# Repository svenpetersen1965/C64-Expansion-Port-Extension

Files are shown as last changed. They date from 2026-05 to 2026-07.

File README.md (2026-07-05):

This is an extension cable thing for the C64 Expansion Port, consisting of two PCBs, one fits into the C64, the other provices an expansion port connector, which are connected via a ribbon cable. 

Rev. 0 of this project is now built and tested. A 25cm ribbon cable is good, a 100cm ribbon cable is too long.

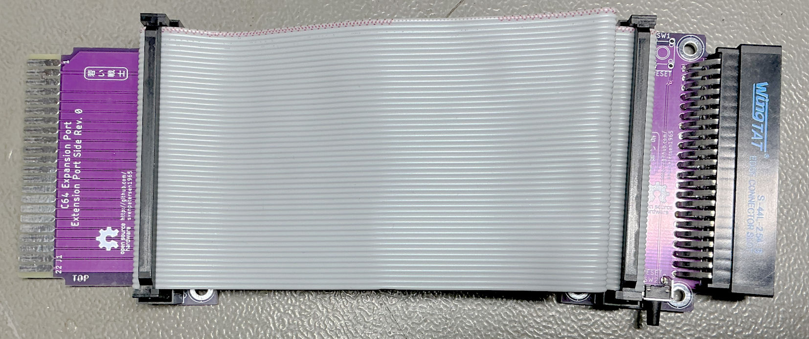
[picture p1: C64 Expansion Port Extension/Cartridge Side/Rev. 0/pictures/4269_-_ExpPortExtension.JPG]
Expansion Port Extansion


For User Port and Cassette Port Extension Cable see: <a href="https://github.com/svenpetersen1965/Commodore-Port-Breakout">Commodore Port Breakout</a>

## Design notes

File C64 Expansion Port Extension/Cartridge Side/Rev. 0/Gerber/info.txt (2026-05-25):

      
       Board: C64 Exp cartridge
       Rev.:  0
  
       Files:
       ======
  
       All Gerber files are generated in extended gerber format (RS274X)
       *.TOP        : Film top copper
       *.BOT        :  -"- bottom copper
       *.STC        :  -"- top soldermask 
       *.STS        :  -"- bottom soldermask
       *.PLC        :  -"- silk screen top
       *.PLS        :  -"- silk screen bottom
       *.DK         : Drills plated Through (Excellon)
       *.NDK        : Drills not plated Through (Excellon)
       *.OUT        : Board outline

       Board Size:
       ===========
       Length     :   72.0 mm
       Width      :   48.0 mm
       Thickness  :   1.6 mm
       Material   :   FR 4
       Copper     :   35 um
       Surface    :   HASL
       
       Remarks:
       ========

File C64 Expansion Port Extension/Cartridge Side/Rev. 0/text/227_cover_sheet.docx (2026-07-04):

Project Documentation

C64 Expansion Board Extension
Cartridge Side

Project number: 227

Revision: 0

Date: 25.05.2026


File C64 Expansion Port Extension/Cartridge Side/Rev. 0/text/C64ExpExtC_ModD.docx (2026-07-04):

C64 Expansion Port Extension Cartridge Side Rev. 0

Module Description

# Introduction

The purpose of the C64 Expansion Port Extension is to place an Expansion Port connector at a desired location and connect the actual C64 Expansion Port via a ribbon cable. The maximum length of said ribbon cable is not yet determined it is >25cm and <100 cm. This board is providing the cartridge connector and a reset switch (two possible positions).

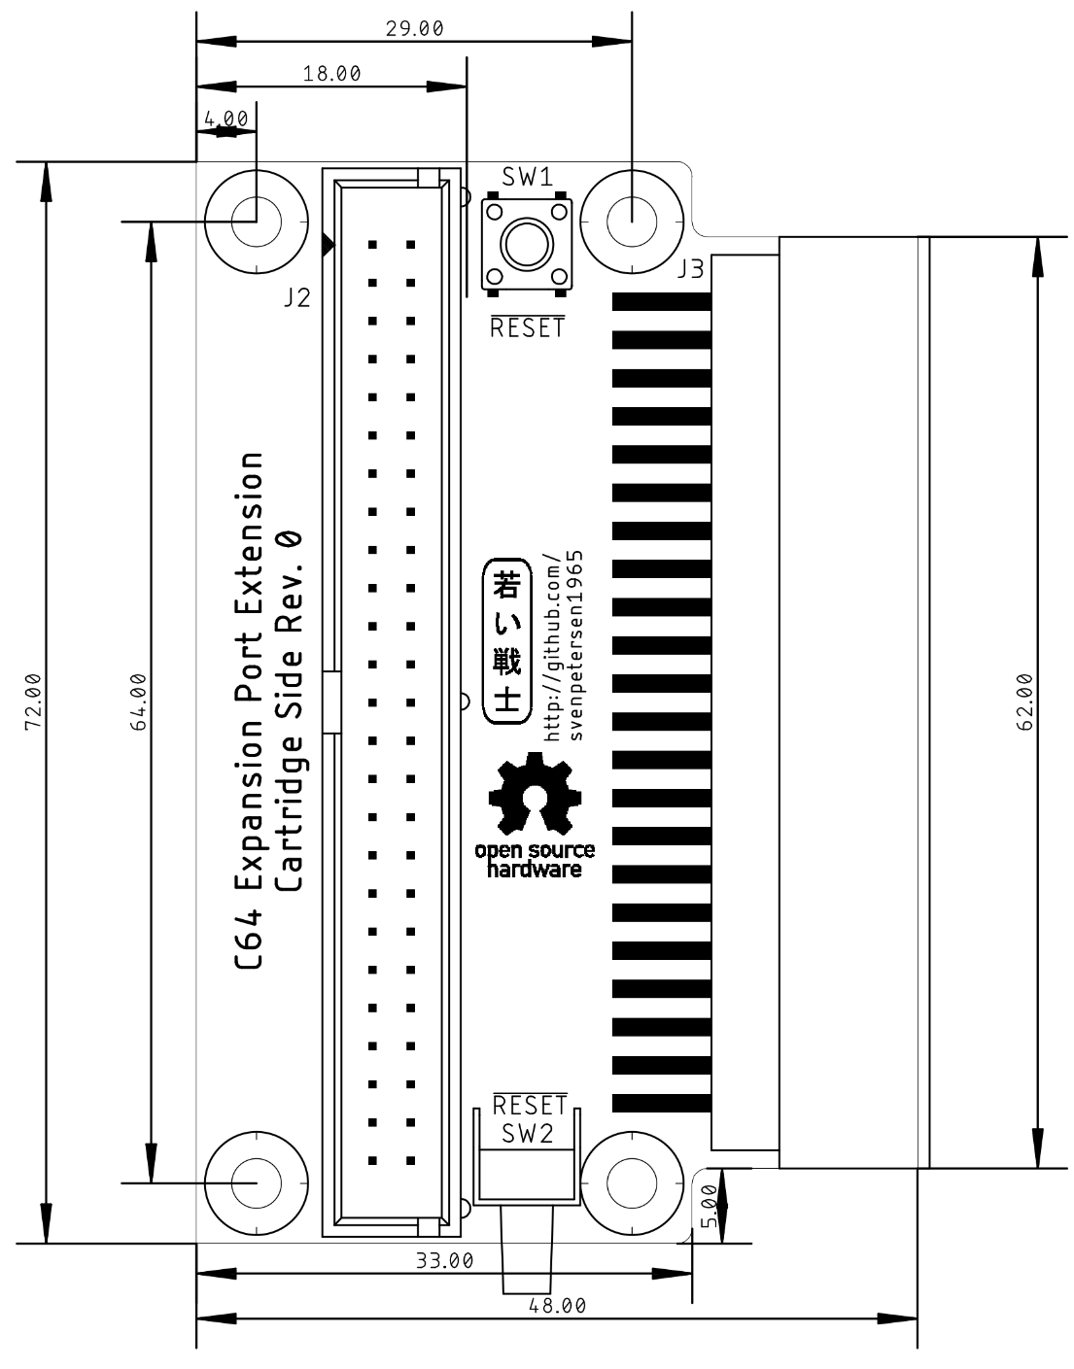
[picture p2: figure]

Figure 1: Dimension of the cartridge side PCB

# Connector Pinouts

## J2 – Break out connector

2x25 box header, 2.54mm pitch

Pin | Signal | Pin | Signal
1 | GND | 2 | GND
3 | +5V | 4 | GND
5 | +5V | 6
7 | +5V | 8
9 | | 10
11 | R / | 12 | PHI2
13 | DOT CLOCK | 14 | A15
15 | | 16 | A14
17 | | 18 | A13
19 | | 20 | A12
21 | | 22 | A11
23 | | 24 | A10
25 | BA | 26 | A9
27 | | 28 | A8
29 | D7 | 30 | A7
31 | D6 | 32 | A6
33 | D5 | 34 | A5
35 | D4 | 36 | A4
37 | D3 | 38 | A3
39 | D2 | 40 | A2
41 | D1 | 42 | A1
43 | D0 | 44 | A0
45 | GND | 46 | GND
47 | GND | 48 | GND
49 | GND | 50 | GND

## J3 – Cartridge Connector

Card Edge Connector 22x2P 2.54mm (0.1“) Right Angle

Pin (TOP) | Signal | Pin | Signal (BOT)
1 | GND | A | GND
2 | +5V | B
3 | +5V | C
4 | | D
5 | R / | E | PHI2
6 | DOT CLOCK | F | A15
7 | | H | A14
8 | | J | A13
9 | | K | A12
10 | | L | A11
11 | | M | A10
12 | BA | N | A9
13 | | P | A8
14 | D7 | R | A7
15 | D6 | S | A6
16 | D5 | T | A5
17 | D4 | U | A4
18 | D3 | V | A3
19 | D2 | W | A2
20 | D1 | X | A1
21 | D0 | Y | A0
22 | GND | Z | GND

# Revision History

## Rev. 0

The prototype is functional with a 25cm ribbon cable.

See test description (Doc.-No. 227-6-02-00)

C64ExpExtC_ModD.docx 04.07.2026 12:59 Drafted by Sven Petersen Page 2 of 2 Doc.-No.: 227-6-01-00

C64ExpExtC_ModD.docx 04.07.2026 12:59 Drafted by Sven Petersen Page 1 of 1 Doc.-No.: 227-6-01-00

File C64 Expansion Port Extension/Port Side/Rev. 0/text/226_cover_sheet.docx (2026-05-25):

Project Documentation

C64 Expansion Board Extension
Port Side

Project number: 226

Revision: 0

Date: 25.05.2026

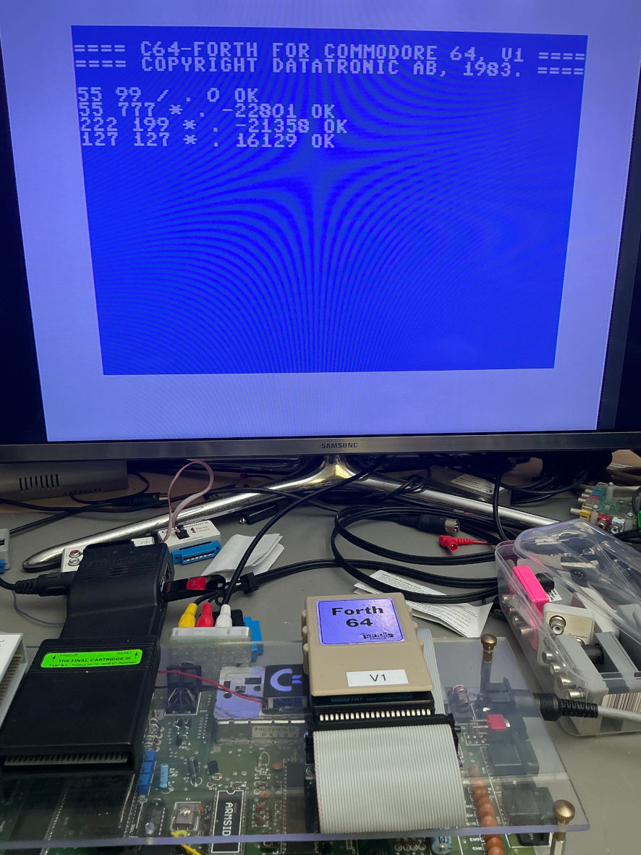
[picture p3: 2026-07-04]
C64 Expansion Port Extension/Cartridge Side/Rev. 0/pictures/4263_-_Forth64_25.JPG

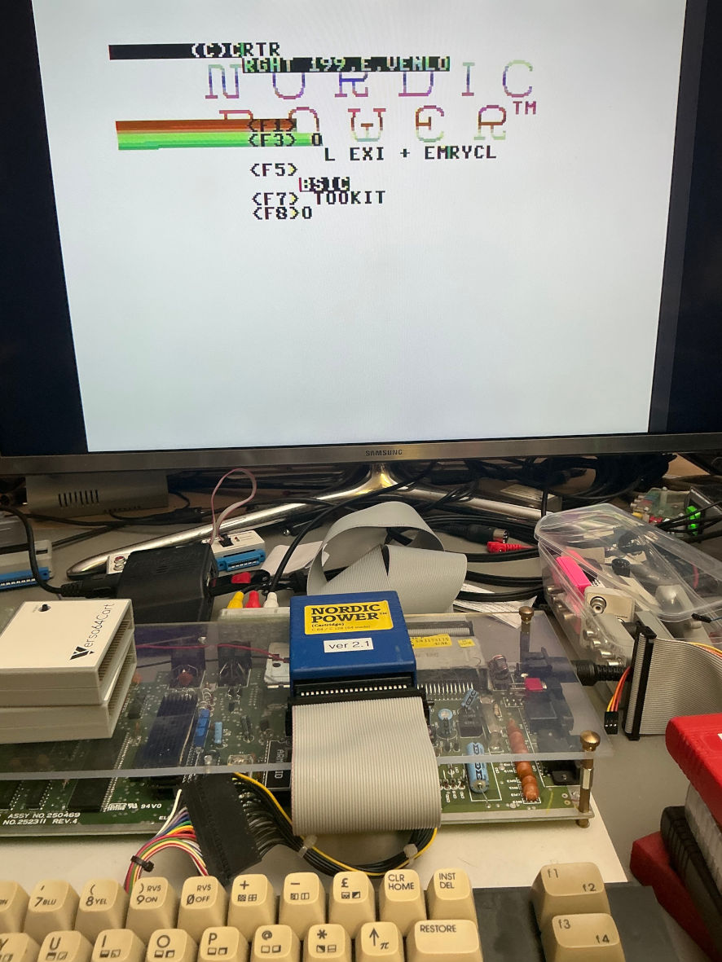
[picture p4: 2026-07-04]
C64 Expansion Port Extension/Cartridge Side/Rev. 0/pictures/4258_-_NordicPower21_100_fail.JPG

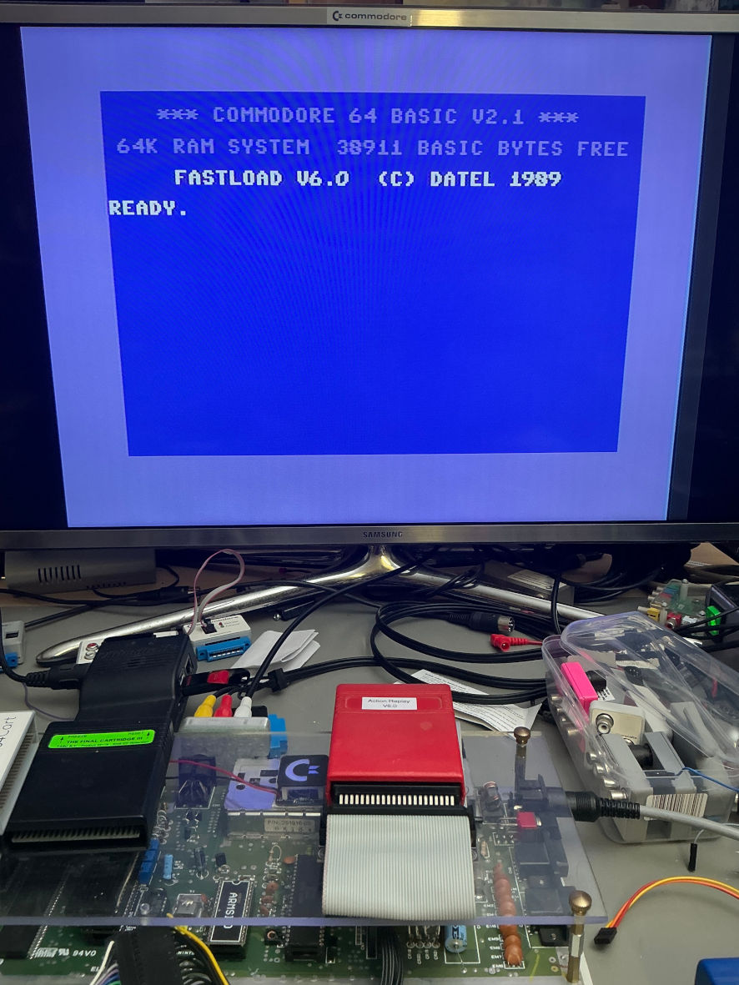
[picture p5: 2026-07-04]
C64 Expansion Port Extension/Cartridge Side/Rev. 0/pictures/4261_-_ActionaReplay25.JPG

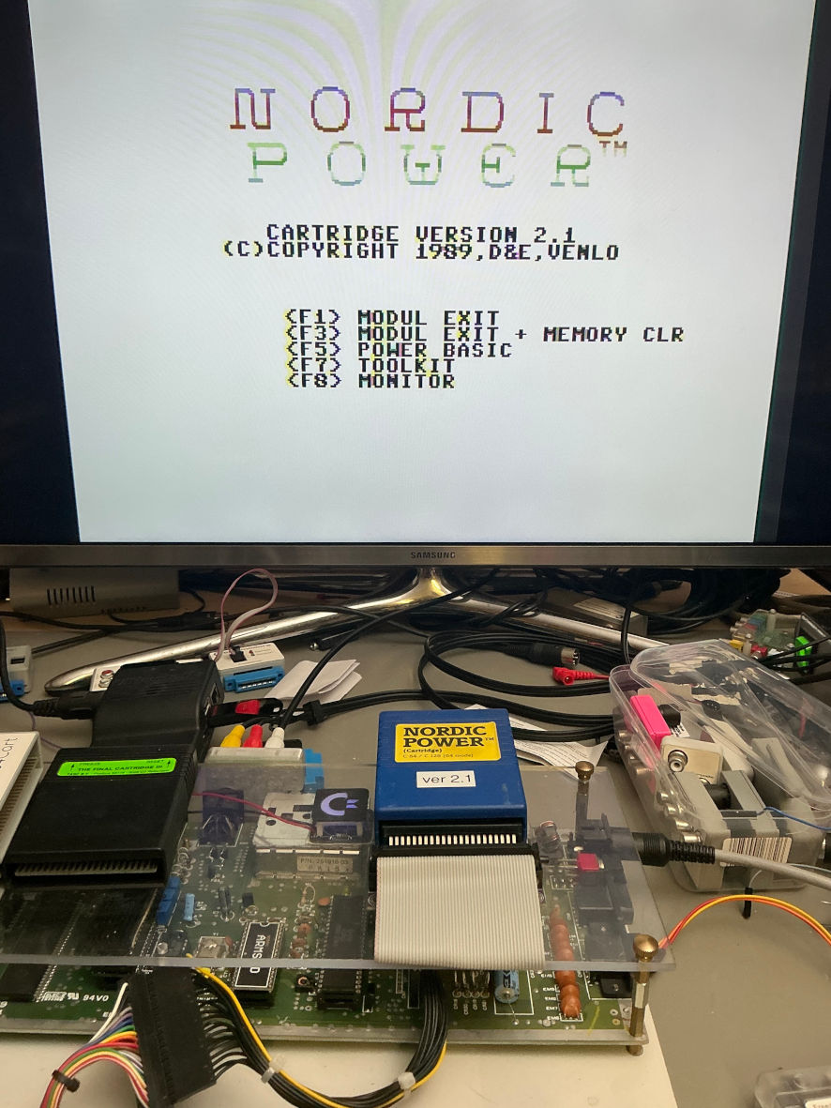
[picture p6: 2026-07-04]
C64 Expansion Port Extension/Cartridge Side/Rev. 0/pictures/4260_-_NordicPower21_25.JPG

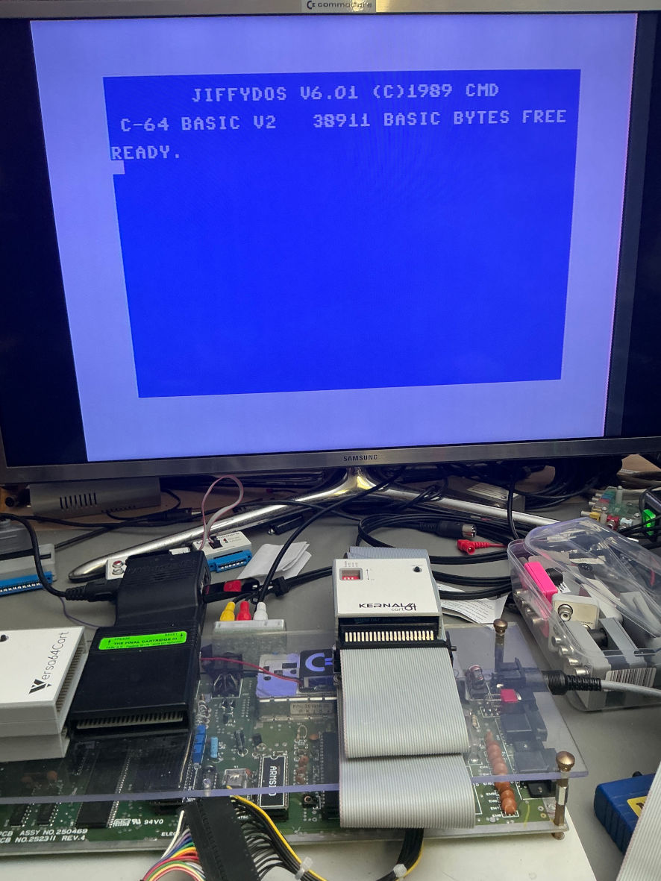
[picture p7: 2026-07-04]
C64 Expansion Port Extension/Cartridge Side/Rev. 0/pictures/4265_-_Kernal64cart100.JPG

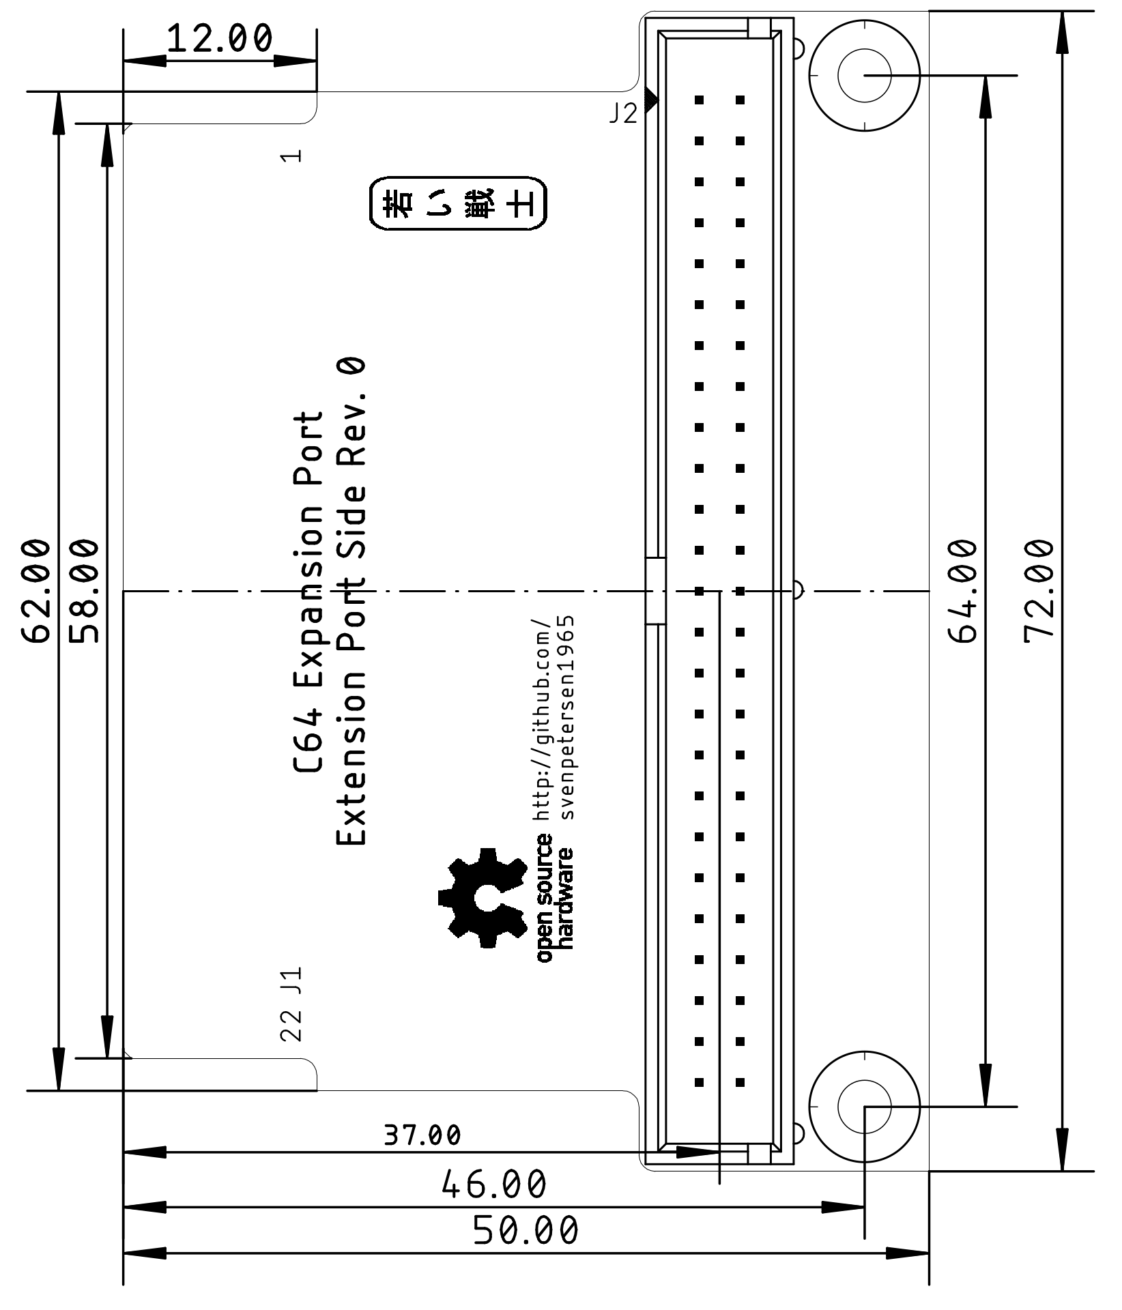
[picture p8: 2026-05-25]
C64 Expansion Port Extension/Port Side/Rev. 0/Pictures/dimensions.png

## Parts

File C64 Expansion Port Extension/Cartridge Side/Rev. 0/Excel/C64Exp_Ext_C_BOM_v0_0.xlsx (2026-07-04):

C64 Expansion Port Extension Cartridge Side Rev. 0
Bill of Material Rev. 0.0
Pos. | Qty | Value | Footprint | Ref.-No. | Comment
1 | 1 | 227-2-01-00 | 2 Layer | PCB Rev. 0 | 2 layer, Cu 35µ, HASL, 72.0mm x 48.0mm, 1.6mm FR4
2 | 1 | 2x25 boxed header | 2X25WV | J2 | 2x25, boxed pin header, e.g. reichelt.de WSL 40G
3 | 1 | 2x22 pin edge connector, 90° | EXPANSION_OUT | J3 | 1/5 x 5pc Industrial Card Edge Slot Socket Connector 22x2P 44P 2.54mm 0.1" Right Angle (https://de.aliexpress.com/item/33029458127.html?sourceType=1)
4 | 1 | JPT1236HB | JTP_1236HB | SW2 | 90° alternative reset switch, AliExpress search term "tact switch 90°"
5 | 1 | JTP-1130 | JTP-1130 | SW1 | Standard 6x6mm tact switch, e.g. Namae JTP-1130 or any other 6x6 tact switch, e.g. reichelt.de JTP-1130 or AliExpress search term "tact switch"
6 | 2 | 2x50 ribbon cable connector, 2.54mm |  |  | See drawing number 227-3-01-00, e.g. reichelt.de PFL 50
7 | 1 | 25cm 50 way AWG28, 1.27mm |  |  | ribbon cable

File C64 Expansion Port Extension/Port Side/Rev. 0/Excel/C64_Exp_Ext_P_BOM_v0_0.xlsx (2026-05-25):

C64 Expansion Port Extension Port Side Rev. 0
Bill of Material Rev. 0.0
Pos. | Qty | Value | Footprint | Ref.-No. | Comment
1 | 1 | 226-2-01-00 | 2 Layer | PCB Rev. 0 | 2 layer, Cu 35µ, HASL, 72.0mm x 50.0mm, 1.6mm FR4
 | 1 | 2x25 box header, 2.54mm | 2X25WV | J2 | 2x25, boxed pin header, e.g. reichelt.de WSL 50G

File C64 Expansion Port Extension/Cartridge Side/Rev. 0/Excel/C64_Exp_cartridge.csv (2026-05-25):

Qty | Value | Device | Package | Parts | Description
4 |  | BOHR3,3 | BOHR3,3 | DRL1, DRL2, DRL3, DRL4
1 |  | PINHD-2X25BOX | 2X25WV | J2
1 | C64-EXPANSION_F | C64-EXPANSION_F | EXPANSION_OUT | J3
1 | JPT1236HB | JPT1236HB | JTP_1236HB | SW2
1 | JTP-1130 | JTP-1130 | JTP-1130 | SW1
1 | OPEN_SOURCE_HW | OPEN_SOURCE_HW | OPENHW | U$22

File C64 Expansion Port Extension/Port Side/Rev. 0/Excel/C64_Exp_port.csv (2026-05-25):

Qty | Value | Device | Package | Parts | Description
2 |  | BOHR3,3 | BOHR3,3 | DRL1, DRL2
1 |  | PINHD-2X25BOX | 2X25WV | J2
1 | C64-EXPANSIONP | C64-EXPANSIONP | EXPPORT | J1
1 | OPEN_SOURCE_HW | OPEN_SOURCE_HW | OPENHW | U$22

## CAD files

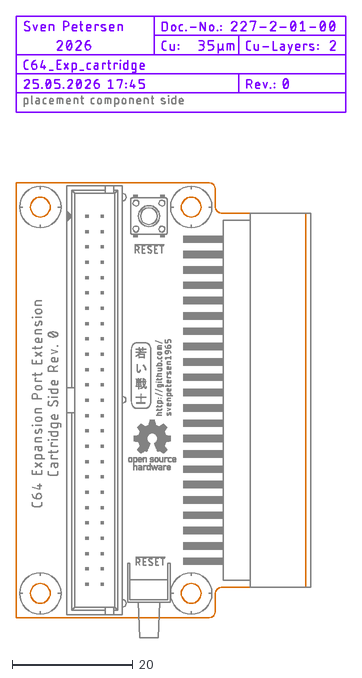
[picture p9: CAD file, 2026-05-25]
C64 Expansion Port Extension/Cartridge Side/Rev. 0/dxf/C64_Exp_cartridge.dxf
54.6 x 103.0

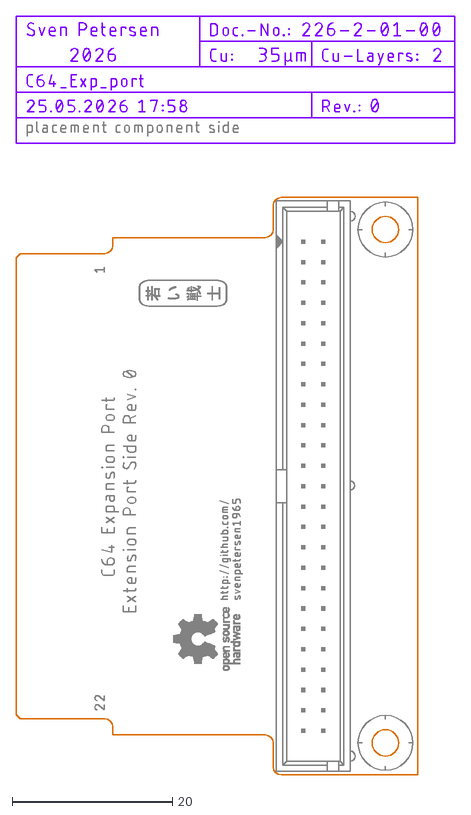
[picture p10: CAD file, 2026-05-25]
C64 Expansion Port Extension/Port Side/Rev. 0/dxf/C64_Exp_port.dxf
54.6 x 94.6

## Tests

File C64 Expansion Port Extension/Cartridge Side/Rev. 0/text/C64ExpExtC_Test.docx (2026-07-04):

C64 Expansion Port Extension Cartridge Side Rev. 0

Test Description

# Test Setup

- C64 short board
- C64 Expansion Port Extension, Port Side & Cartridge Side PCB Rev. 0
- Two 50-way ribbon cables, the lengths are 25cm and 100cm
- A variety of cartridges

# Test Execution

The complete Expansion Port Extension was connected to the C64 expansion port on one side and the cartridge on the other side. Then, the C64 was switched on and different functions of the cartridge were tested.

Cartridge | 25cm cable | 100cm cable
Versa64cart | ☑ | ☑
Easy Flash | ☑ | ☑
Kung Fu Flash | ☑ | ☑
Epyx Fastload | ☑ | ☑
The Final Cartridge III | ☑ | ☑
Ultimate II+ | ☑ | ☑
The Final Cartridge III+ | ☑ | ☒
Forth 64 | ☑ | ☒
Nordic Power 7.2 | ☑ | ☒
Nordic Power 2.1 | ☑ | ☒
Action Replay 6.0 | ☑ | ☒
Ms PAC-MAN | ☑ | ☒
Power Cartridge | ☑ | ☑

# Conclusion

The Expansion Port Extension Rev. 0 is functional. The cable length is influencing the proper function of the cartridge, though. A 25cm ribbon cable is always working, a 100cm ribbon cable is not recommended. The maximum cable length rages between those lengths.

C64ExpExtC_Test.docx 04.07.2026 12:58 Drafted by Sven Petersen Page 2 of 2 Doc.-No.: 227-6-01-00

C64ExpExtC_Test.docx 04.07.2026 12:58 Drafted by Sven Petersen Page 1 of 1 Doc.-No.: 227-6-02-00

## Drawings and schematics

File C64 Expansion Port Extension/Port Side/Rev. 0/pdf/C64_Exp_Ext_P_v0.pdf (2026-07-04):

# Project Documentation

## C64 Expansion Board Extension Port Side

## Project number: 226

## Revision: 0

## Date: 25.05.2026

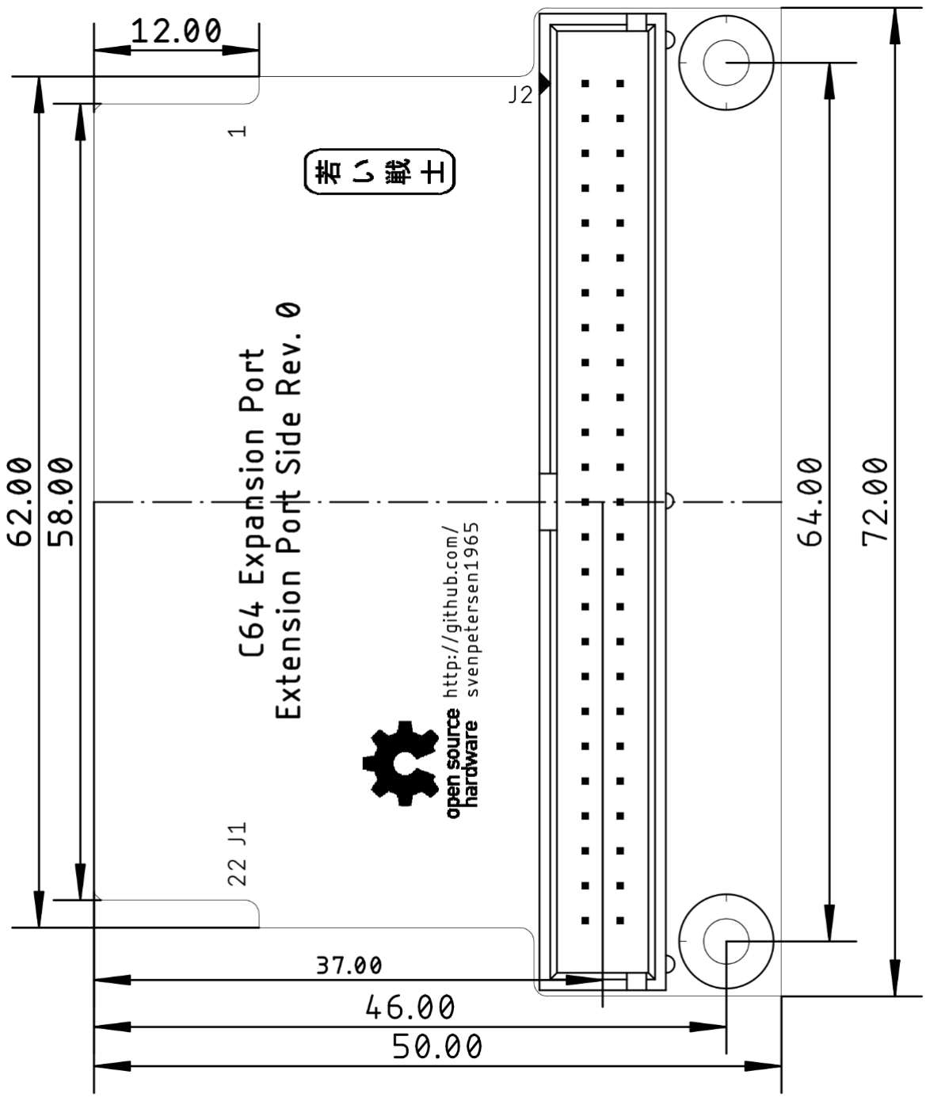
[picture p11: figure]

C64ExpExtP_ModD.docx | | 04.07.2026 13:01
Drafted by Sven Petersen | Page 1 of 3 | Doc.-No.: 226-6-01-00

### C64 Expansion Port Extension Port Side Rev. 0

### Module Description

## Introduction

The purpose of the C64 Expansion Port Extension is to place an Expansion Port connector at a desired location and connect the actual C64 Expansion Port via a ribbon cable. The maximum length of said ribbon cable is not yet determined. This board is connected to the C64 itself.

Figure 1: Dimension of the port side PCB

C64ExpExtP_ModD.docx | | 04.07.2026 13:01
Drafted by Sven Petersen | Page 2 of 3 | Doc.-No.: 226-6-01-00

## Connector Pinouts

### J1 – Expansion Port

Pin (TOP) Signal | Pin Signal (BOT)
1 | GND | A | GND
2 | +5V | B | ROMH
3 | +5V | C | RESET
4 | IRQ | D | NMI
5 | R / W | E | PHI2
6 | DOT CLOCK | F | A15
7 | I/O1 | H | A14
8 | GAME | J | A13
9 | EXROM | K | A12
10 | I/O2 | L | A11
11 | ROML | M | A10
12 | BA | N | A9
13 | DMA | P | A8
14 | D7 | R | A7
15 | D6 | S | A6
16 | D5 | T | A5
17 | D4 | U | A4
18 | D3 | V | A3
19 | D2 | W | A2
20 | D1 | X | A1
21 | D0 | Y | A0
22 | GND | Z | GND

### J2 – Break out connector

2x25 box header, 2.54mm pitch

Pin Signal | Pin Signal
1 | GND | 2 | GND
3 | +5V | 4 | GND
5 | +5V | 6 | ROMH
7 | +5V | 8 | RESET
9 | IRQ | 10 | NMI
11 | R / W | 12 | PHI2
13 | DOT CLOCK | 14 | A15
15 | I/O1 | 16 | A14
17 | GAME | 18 | A13
19 | EXROM | 20 | A12

C64ExpExtP_ModD.docx | | 04.07.2026 13:01
Drafted by Sven Petersen | Page 3 of 3 | Doc.-No.: 226-6-01-00
Pin Signal | Pin Signal
21 | I/O2 | 22 | A11
23 | ROML | 24 | A10
25 | BA | 26 | A9
27 | DMA | 28 | A8
29 | D7 | 30 | A7
31 | D6 | 32 | A6
33 | D5 | 34 | A5
35 | D4 | 36 | A4
37 | D3 | 38 | A3
39 | D2 | 40 | A2
41 | D1 | 42 | A1
43 | D0 | 44 | A0
45 | GND | 46 | GND
47 | GND | 48 | GND
49 | GND | 50 | GND

## Revision History

### Rev. 0

The prototype is functional with a 25cm cable

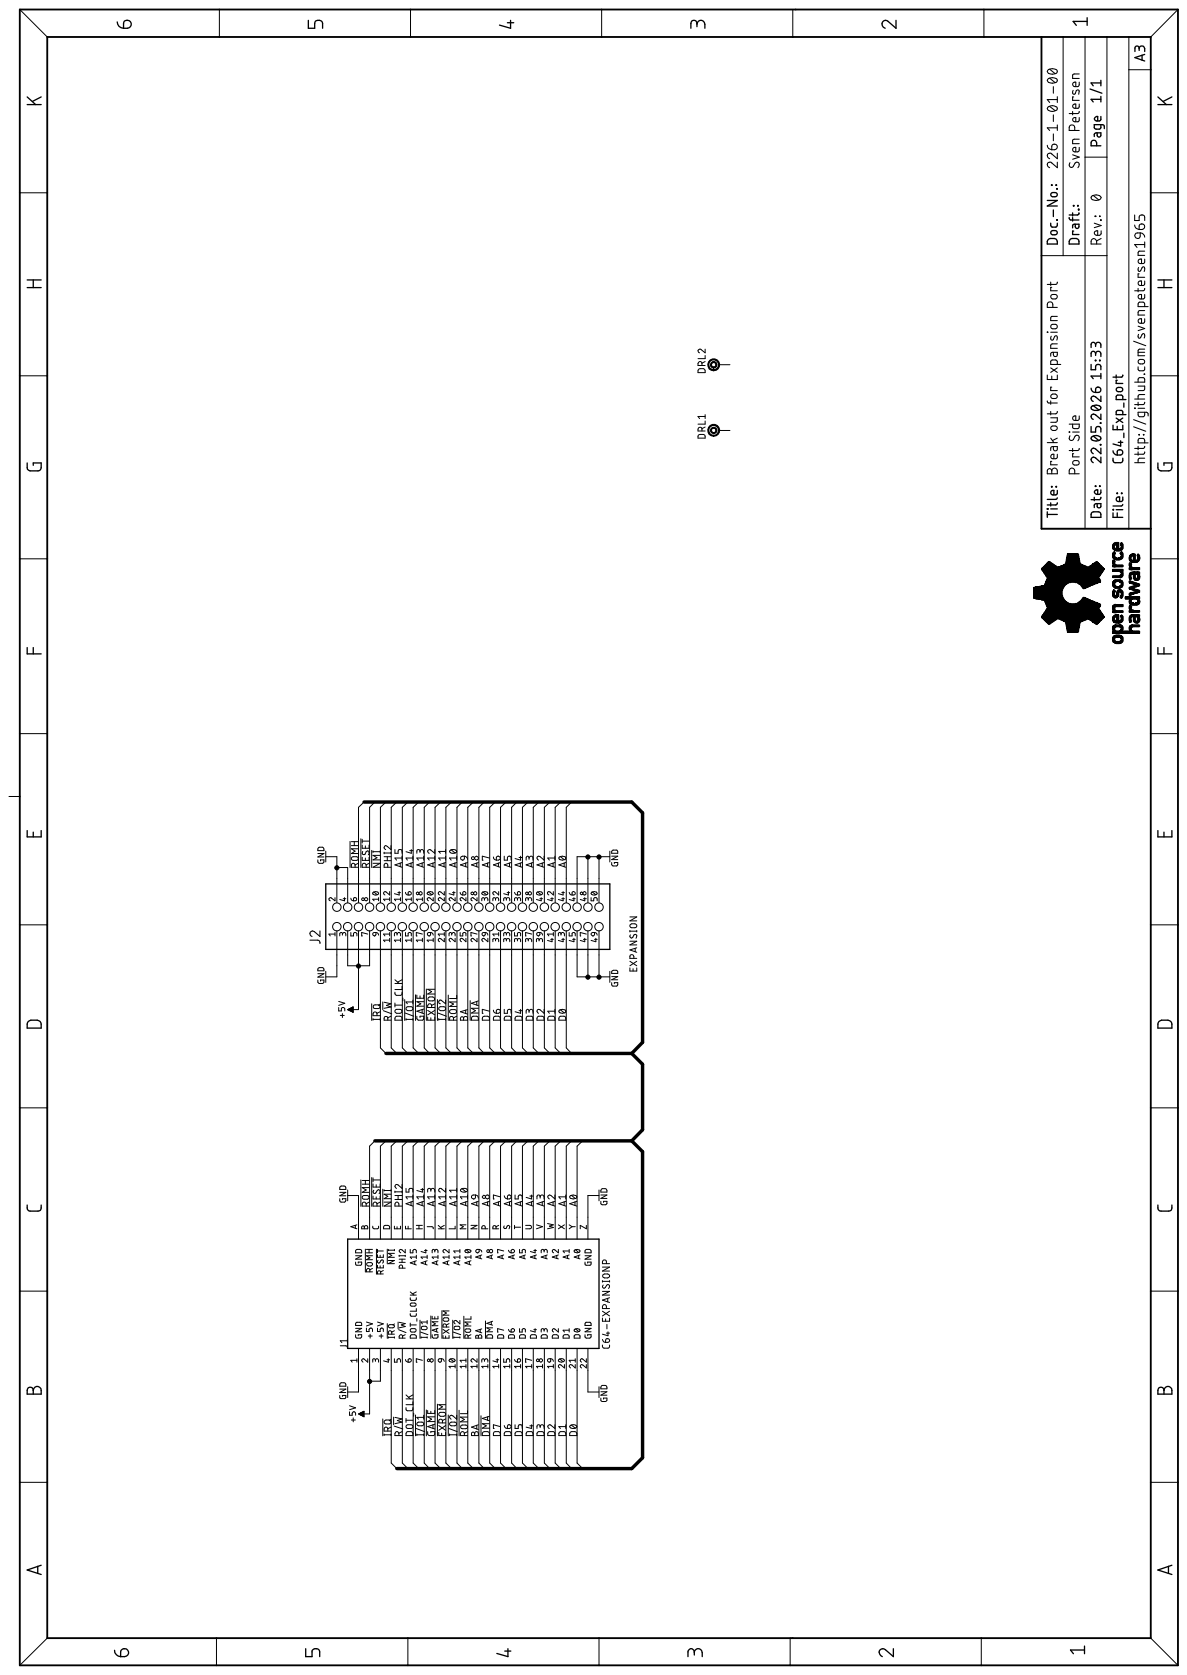
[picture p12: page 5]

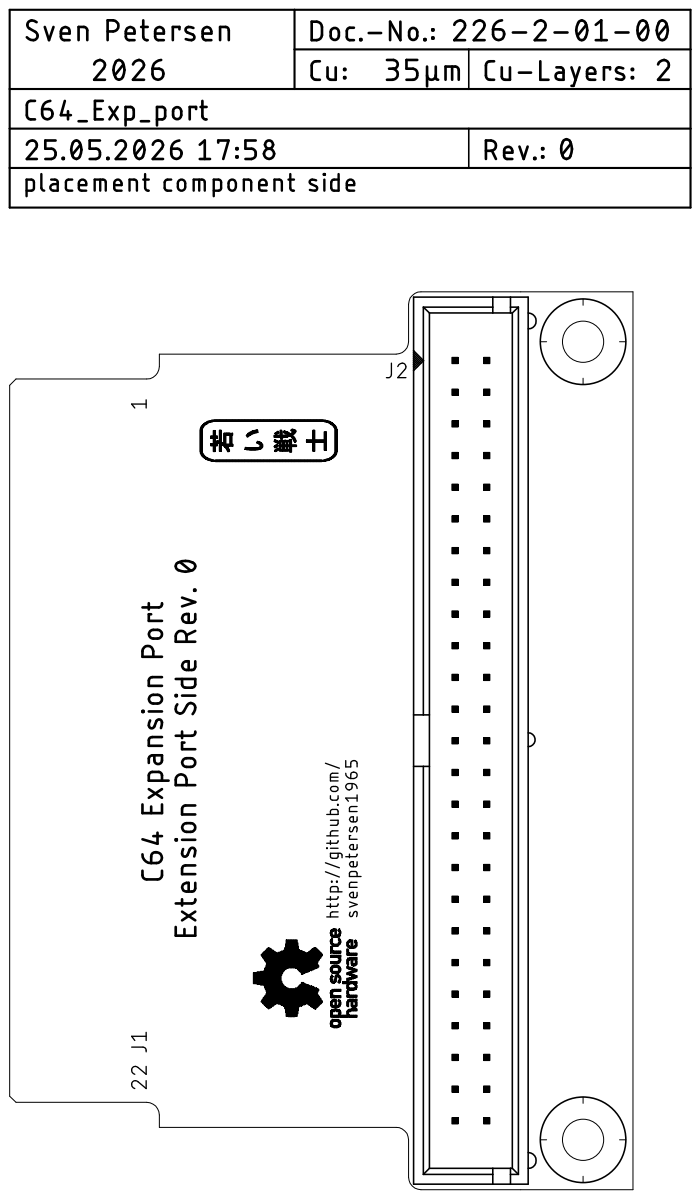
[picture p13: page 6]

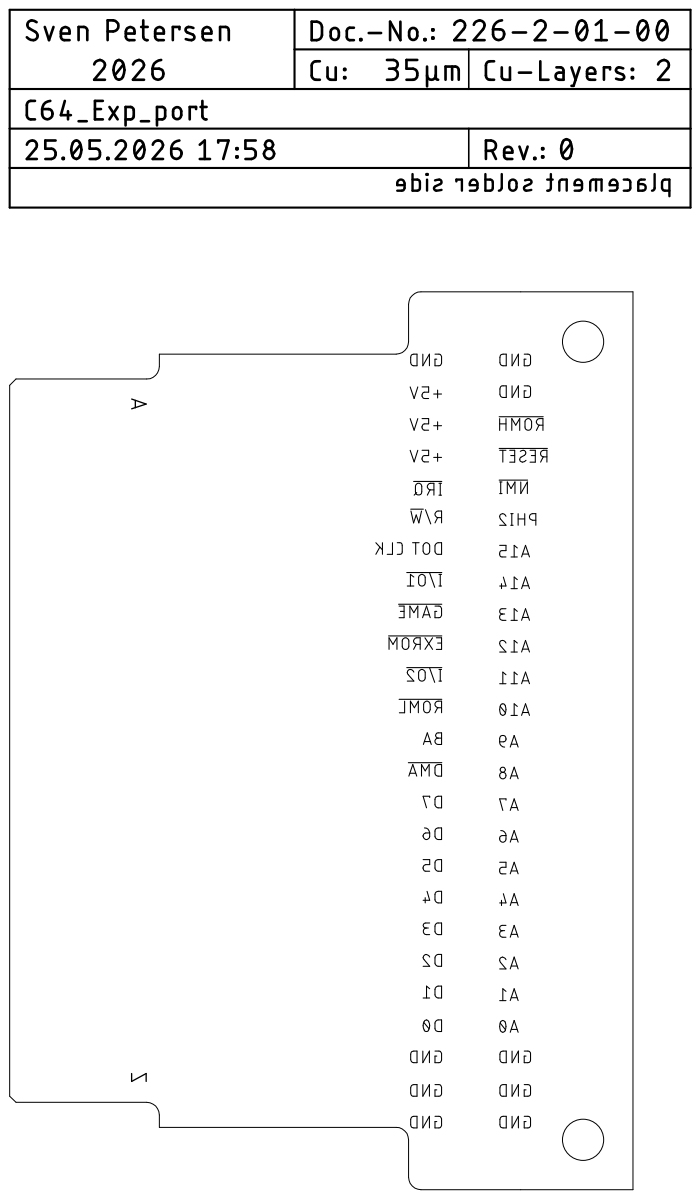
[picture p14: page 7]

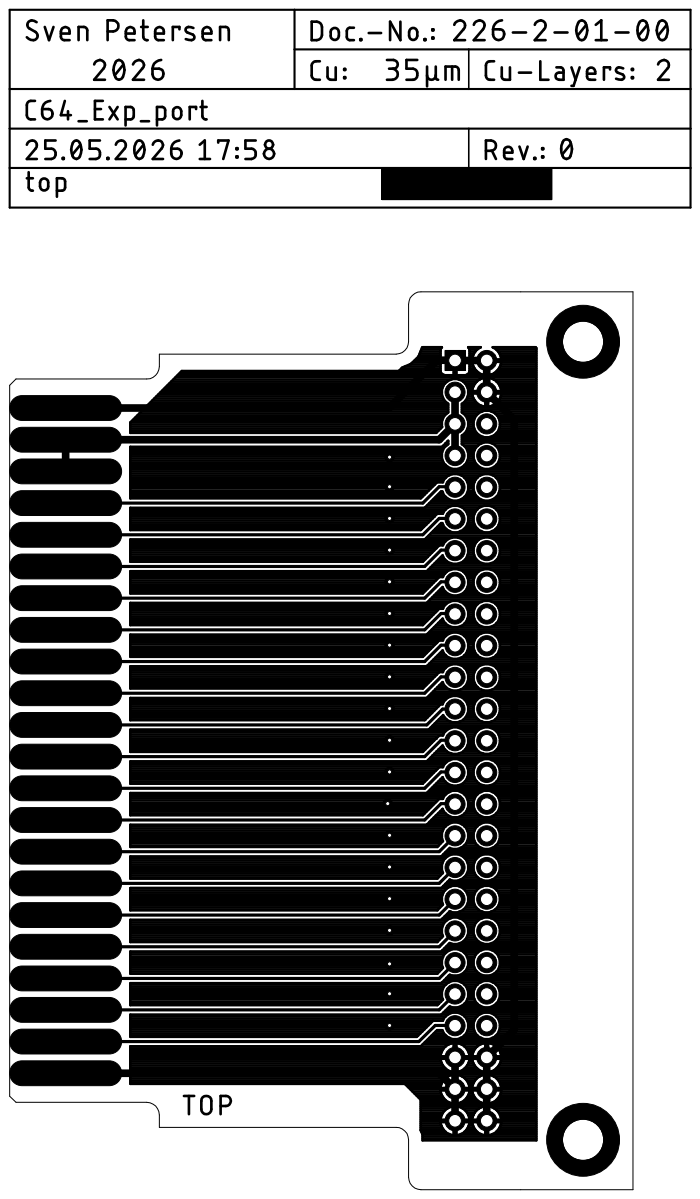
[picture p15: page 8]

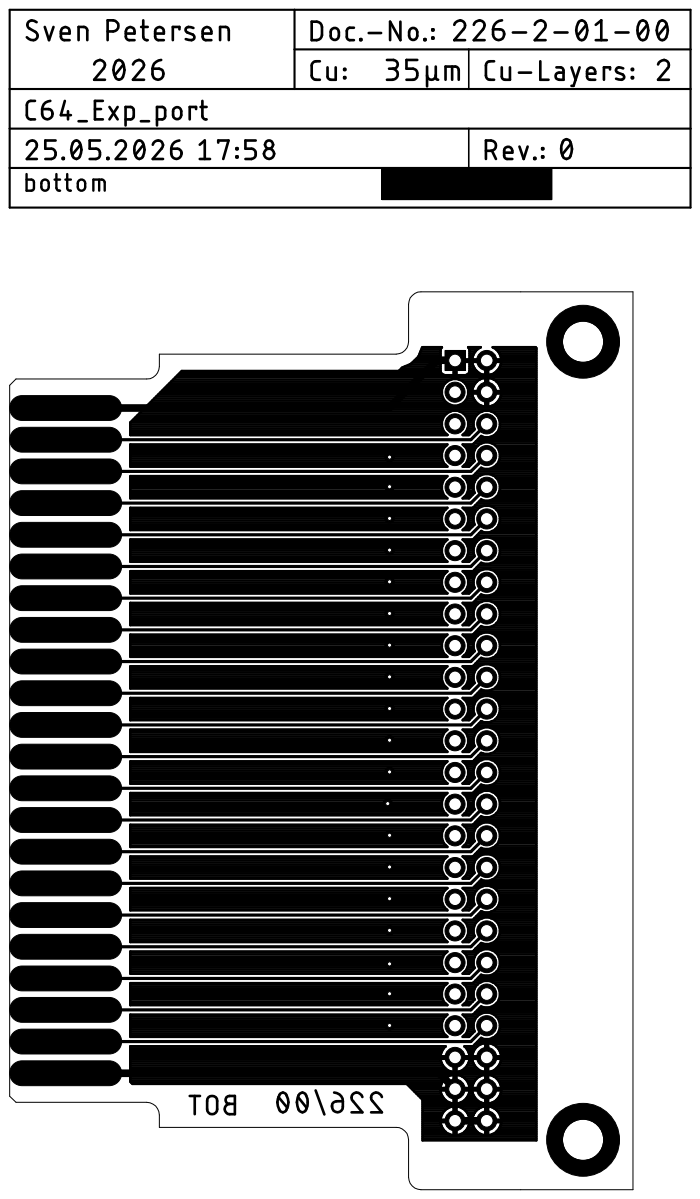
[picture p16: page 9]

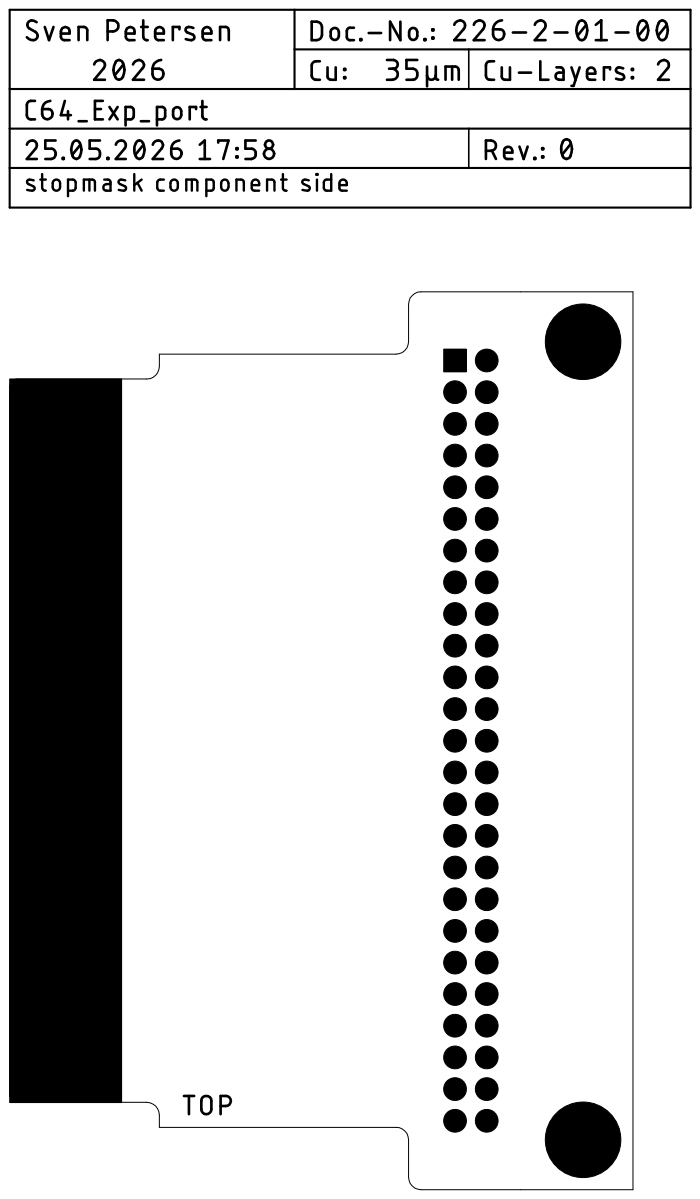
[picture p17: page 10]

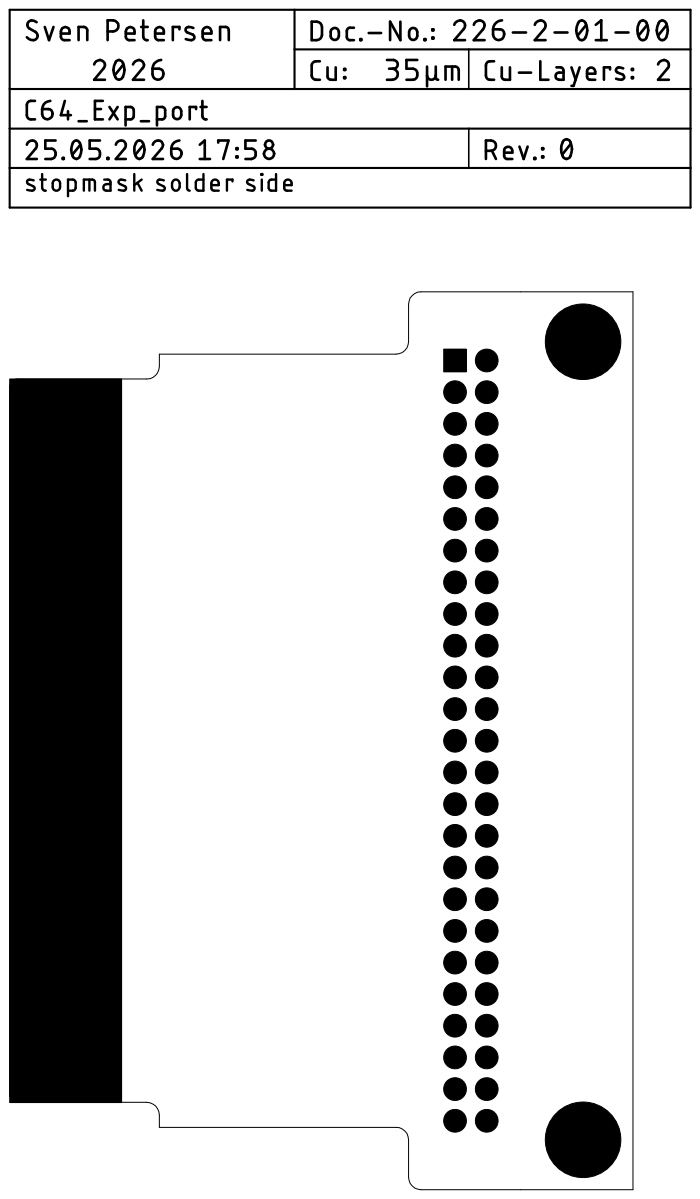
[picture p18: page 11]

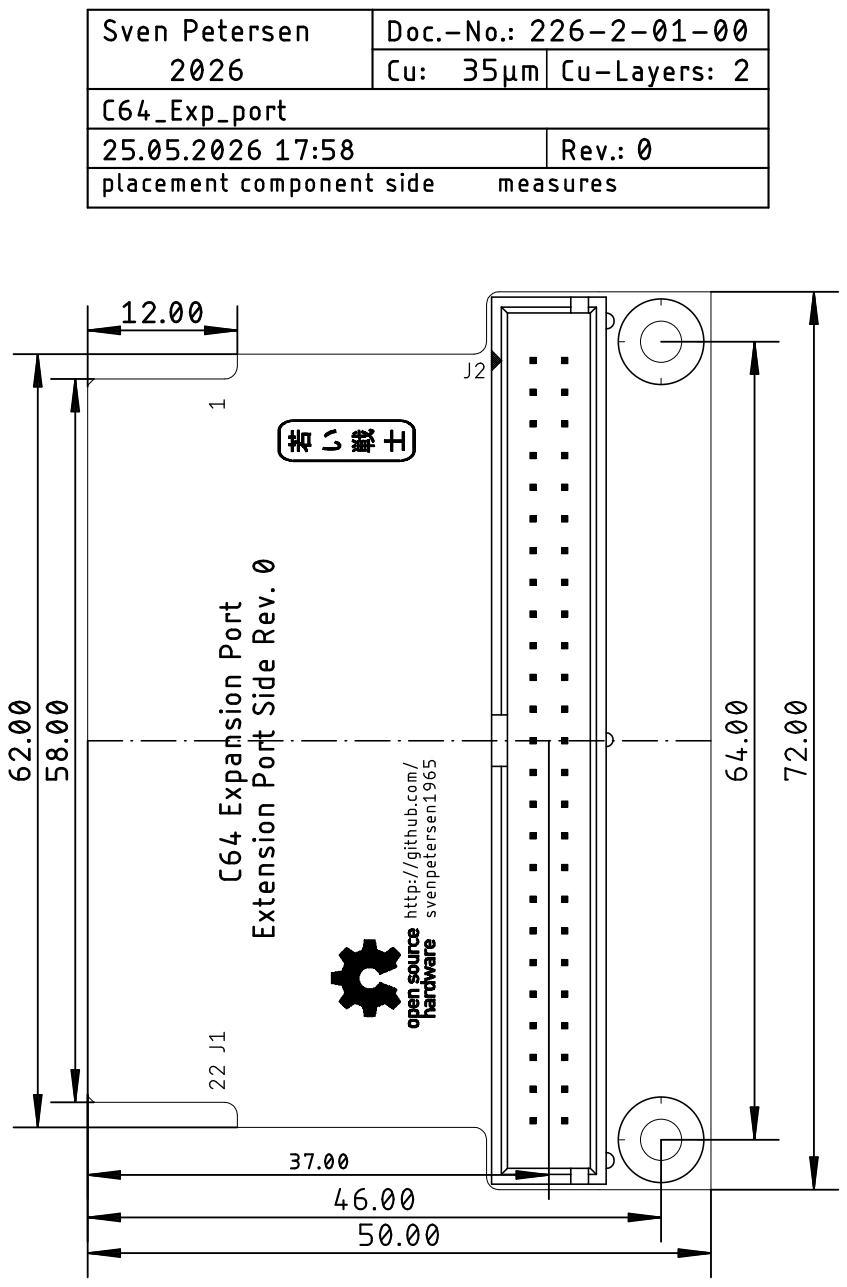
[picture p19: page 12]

Pos. Qty Value Footprint Ref.-No. Comment

1 1 226-2-01-00 2 Layer PCB Rev. 0 2 layer, Cu 35µ, HASL, 72.0mm x 50.0mm, 1.6mm FR4

1 2x25 box header, 2.54mm 2X25WV J2 2x25, boxed pin header, e.g. reichelt.de WSL 50G

## C64 Expansion Port Extension Port Side Rev. 0

## Bill of Material Rev. 0.0

C64_Exp_Ext_P_BOM_v0_0.xlsx

Drafted by Sven Petersen Page 1 of 1

25.05.2026 21:46
Doc.No.: 226-5-01-00.0

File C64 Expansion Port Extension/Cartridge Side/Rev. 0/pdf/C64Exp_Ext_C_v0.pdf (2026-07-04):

# Project Documentation

## C64 Expansion Board Extension Cartridge Side

## Project number: 227

## Revision: 0

## Date: 25.05.2026

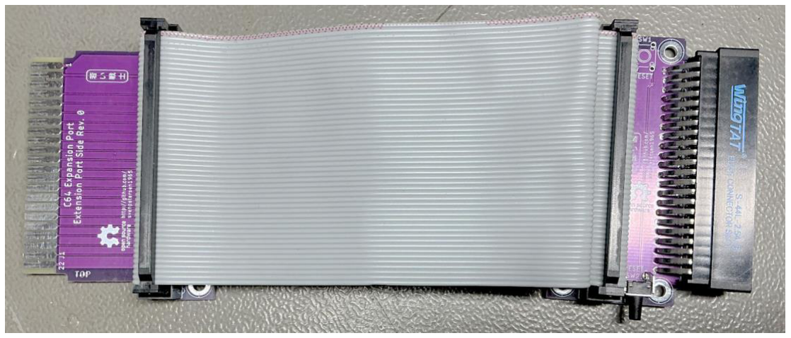
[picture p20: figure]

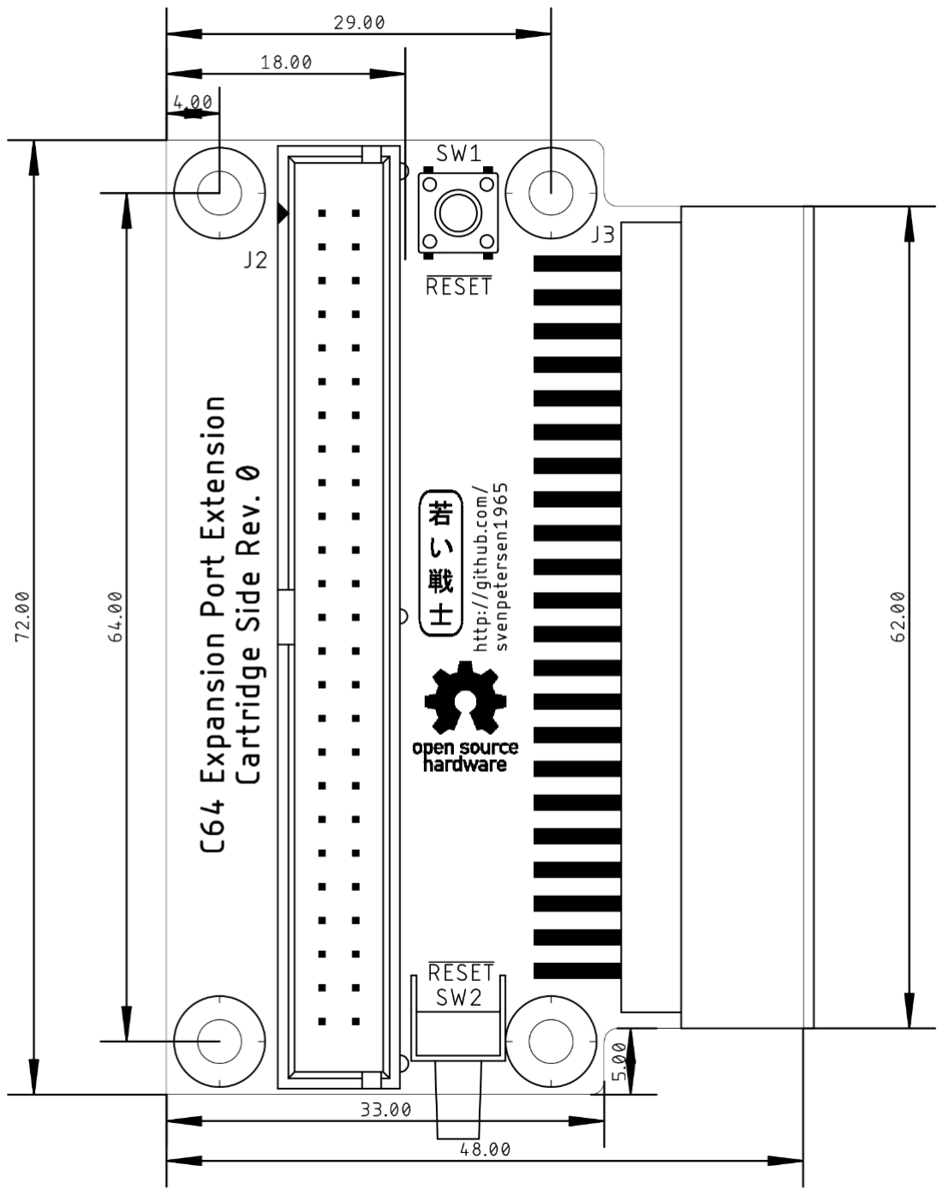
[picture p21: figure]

C64ExpExtC_ModD.docx | | 04.07.2026 12:59
Drafted by Sven Petersen | Page 1 of 3 | Doc.-No.: 227-6-01-00

### C64 Expansion Port Extension Cartridge Side Rev. 0

### Module Description

## Introduction

The purpose of the C64 Expansion Port Extension is to place an Expansion Port connector at a desired location and connect the actual C64 Expansion Port via a ribbon cable. The maximum length of said ribbon cable is not yet determined it is >25cm and <100 cm. This board is providing the cartridge connector and a reset switch (two possible positions).

Figure 1: Dimension of the cartridge side PCB

C64ExpExtC_ModD.docx | | 04.07.2026 12:59
Drafted by Sven Petersen | Page 2 of 3 | Doc.-No.: 227-6-01-00

## Connector Pinouts

### J2 – Break out connector

2x25 box header, 2.54mm pitch

Pin Signal | Pin Signal
1 | GND | 2 | GND
3 | +5V | 4 | GND
5 | +5V | 6 | ROMH
7 | +5V | 8 | RESET
9 | IRQ | 10 | NMI
11 | R / W | 12 | PHI2
13 | DOT CLOCK | 14 | A15
15 | I/O1 | 16 | A14
17 | GAME | 18 | A13
19 | EXROM | 20 | A12
21 | I/O2 | 22 | A11
23 | ROML | 24 | A10
25 | BA | 26 | A9
27 | DMA | 28 | A8
29 | D7 | 30 | A7
31 | D6 | 32 | A6
33 | D5 | 34 | A5
35 | D4 | 36 | A4
37 | D3 | 38 | A3
39 | D2 | 40 | A2
41 | D1 | 42 | A1
43 | D0 | 44 | A0
45 | GND | 46 | GND
47 | GND | 48 | GND
49 | GND | 50 | GND

### J3 – Cartridge Connector Card Edge Connector 22x2P 2.54mm (0.1“) Right Angle

Pin (TOP) Signal | Pin Signal (BOT)
1 | GND | A | GND
2 | +5V | B | ROMH
3 | +5V | C | RESET
4 | IRQ | D | NMI
5 | R / W | E | PHI2
6 | DOT CLOCK | F | A15

C64ExpExtC_ModD.docx | | 04.07.2026 12:59
Drafted by Sven Petersen | Page 3 of 3 | Doc.-No.: 227-6-01-00
Pin (TOP) Signal | Pin Signal (BOT)
7 | I/O1 | H | A14
8 | GAME | J | A13
9 | EXROM | K | A12
10 | I/O2 | L | A11
11 | ROML | M | A10
12 | BA | N | A9
13 | DMA | P | A8
14 | D7 | R | A7
15 | D6 | S | A6
16 | D5 | T | A5
17 | D4 | U | A4
18 | D3 | V | A3
19 | D2 | W | A2
20 | D1 | X | A1
21 | D0 | Y | A0
22 | GND | Z | GND

## Revision History

### Rev. 0

The prototype is functional with a 25cm ribbon cable.

See test description (Doc.-No. 227-6-02-00)

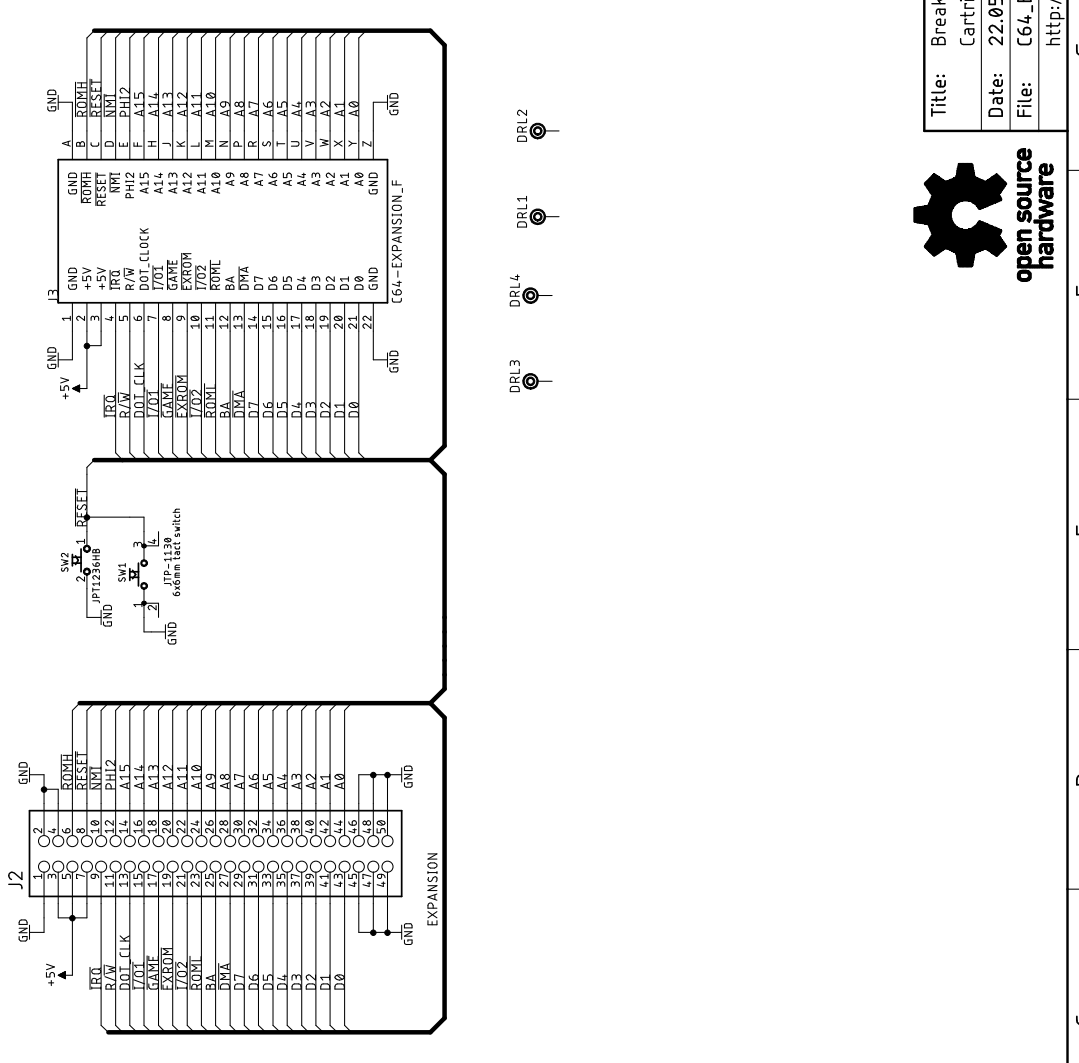
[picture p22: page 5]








Rev.: 0; Datei:; Titel:; Dok.-Nr.: 227-3-01-00; Datum: 04.07.2026 20:41; C64 Expansion Port

Bearb.: Sven Petersen

Extension Cable ExtCab.SKF 1 2x25 way IDC Ribbon Cable Connector, 2.54mm pitch 25cm Ribbon Cable, 50-way, AWG28, 1.27mm pitch This is the length for a long board C64 mainboard. It varies for a short board or an Ultimate64. 1

https://github.com/svenpetersen1965

C64ExpExtC_Test.docx | | 04.07.2026 12:58
Drafted by Sven Petersen | Page 1 of 1 | Doc.-No.: 227-6-02-00

### C64 Expansion Port Extension Cartridge Side Rev. 0

### Test Description

## Test Setup

- C64 short board
- C64 Expansion Port Extension, Port Side & Cartridge Side PCB Rev. 0
- Two 50-way ribbon cables, the lengths are 25cm and 100cm
- A variety of cartridges

Test Execution

The complete Expansion Port Extension was connected to the C64 expansion port on one side and the cartridge on the other side. Then, the C64 was switched on and different functions of the cartridge were tested.

Cartridge | 25cm cable | 100cm cable
Versa64cart | ☑ | ☑
Easy Flash | ☑ | ☑
Kung Fu Flash | ☑ | ☑
Epyx Fastload | ☑ | ☑
The Final Cartridge III | ☑ | ☑
Ultimate II+ | ☑ | ☑
The Final Cartridge III+ | ☑ | ☒
Forth 64 | ☑ | ☒
Nordic Power 7.2 | ☑ | ☒
Nordic Power 2.1 | ☑ | ☒
Action Replay 6.0 | ☑ | ☒
Ms PAC-MAN | ☑ | ☒
Power Cartridge | ☑ | ☑
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

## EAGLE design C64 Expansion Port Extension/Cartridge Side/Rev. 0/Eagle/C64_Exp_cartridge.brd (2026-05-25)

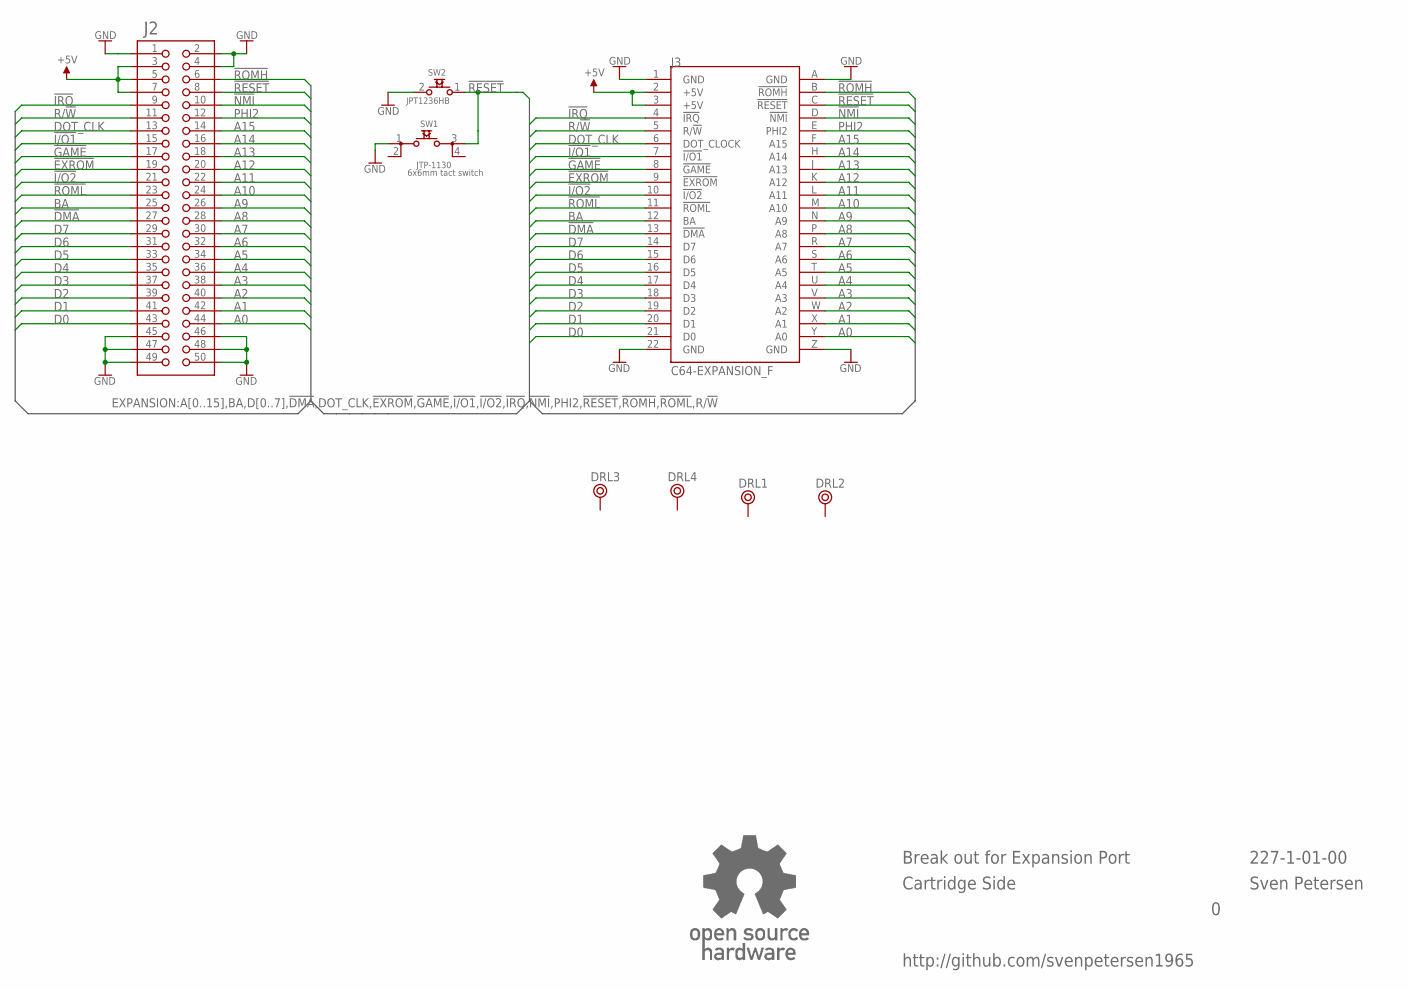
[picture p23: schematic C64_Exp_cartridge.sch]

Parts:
DRL1, DRL2, DRL3, DRL4: BOHR3,3
J2: PINHD-2X25BOX; 2X25WV
J3: C64-EXPANSION_F; EXPANSION_OUT
SW1: JTP-1130
SW2: JPT1236HB; JTP_1236HB
U$22: OPEN_SOURCE_HW; OPENHW

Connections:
!DMA: J2.27, J3.13 (!DMA)
!EXROM: J2.19, J3.9 (!EXROM)
!GAME: J2.17, J3.8 (!GAME)
!I/O1: J2.15, J3.7 (!I/O1)
!I/O2: J2.21, J3.10 (!I/O2)
!IRQ: J2.9, J3.4 (!IRQ)
!NMI: J2.10, J3.D (!NMI)
!RESET: J2.8, J3.C (!RESET), SW1.3, SW2.1
!ROMH: J2.6, J3.B (!ROMH)
!ROML: J2.23, J3.11 (!ROML)
+5V: J2.3, J2.5, J2.7, J3.2 (+5V), J3.3 (+5V)
A0: J2.44, J3.Y (A0)
A1: J2.42, J3.X (A1)
A2: J2.40, J3.W (A2)
A3: J2.38, J3.V (A3)
A4: J2.36, J3.U (A4)
A5: J2.34, J3.T (A5)
A6: J2.32, J3.S (A6)
A7: J2.30, J3.R (A7)
A8: J2.28, J3.P (A8)
A9: J2.26, J3.N (A9)
A10: J2.24, J3.M (A10)
A11: J2.22, J3.L (A11)
A12: J2.20, J3.K (A12)
A13: J2.18, J3.J (A13)
A14: J2.16, J3.H (A14)
A15: J2.14, J3.F (A15)
BA: J2.25, J3.12 (BA)
D0: J2.43, J3.21 (D0)
D1: J2.41, J3.20 (D1)
D2: J2.39, J3.19 (D2)
D3: J2.37, J3.18 (D3)
D4: J2.35, J3.17 (D4)
D5: J2.33, J3.16 (D5)
D6: J2.31, J3.15 (D6)
D7: J2.29, J3.14 (D7)
DOT_CLK: J2.13, J3.6 (DOT_CLOCK)
GND: J2.1, J2.2, J2.4, J2.45, J2.46, J2.47, J2.48, J2.49, J2.50, J3.1 (GND), J3.22 (GND), J3.A (GND), J3.Z (GND), SW1.1, SW2.2
PHI2: J2.12, J3.E (PHI2)
R/!W: J2.11, J3.5 (R/!W)

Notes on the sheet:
Sven Petersen
227-1-01-00
http://github.com/svenpetersen1965
6x6mm tact switch
Break out for Expansion Port
Cartridge Side

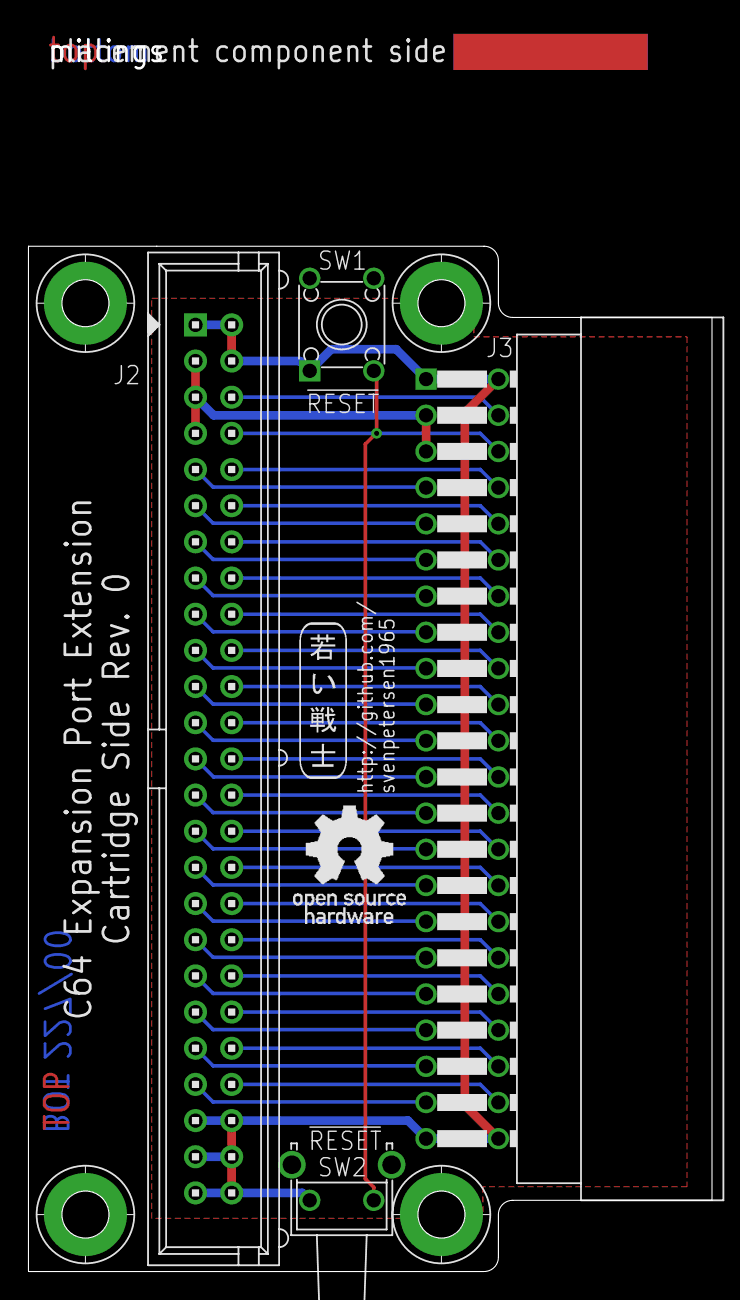
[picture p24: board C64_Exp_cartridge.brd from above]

Board: 2 copper layers, 48.0 x 72.0 mm, 12 parts (0 on the bottom side), 40 nets.

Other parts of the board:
U$20: 2LAYER
U$21: PCB-TITLE/
U$23: SVEN_TAG

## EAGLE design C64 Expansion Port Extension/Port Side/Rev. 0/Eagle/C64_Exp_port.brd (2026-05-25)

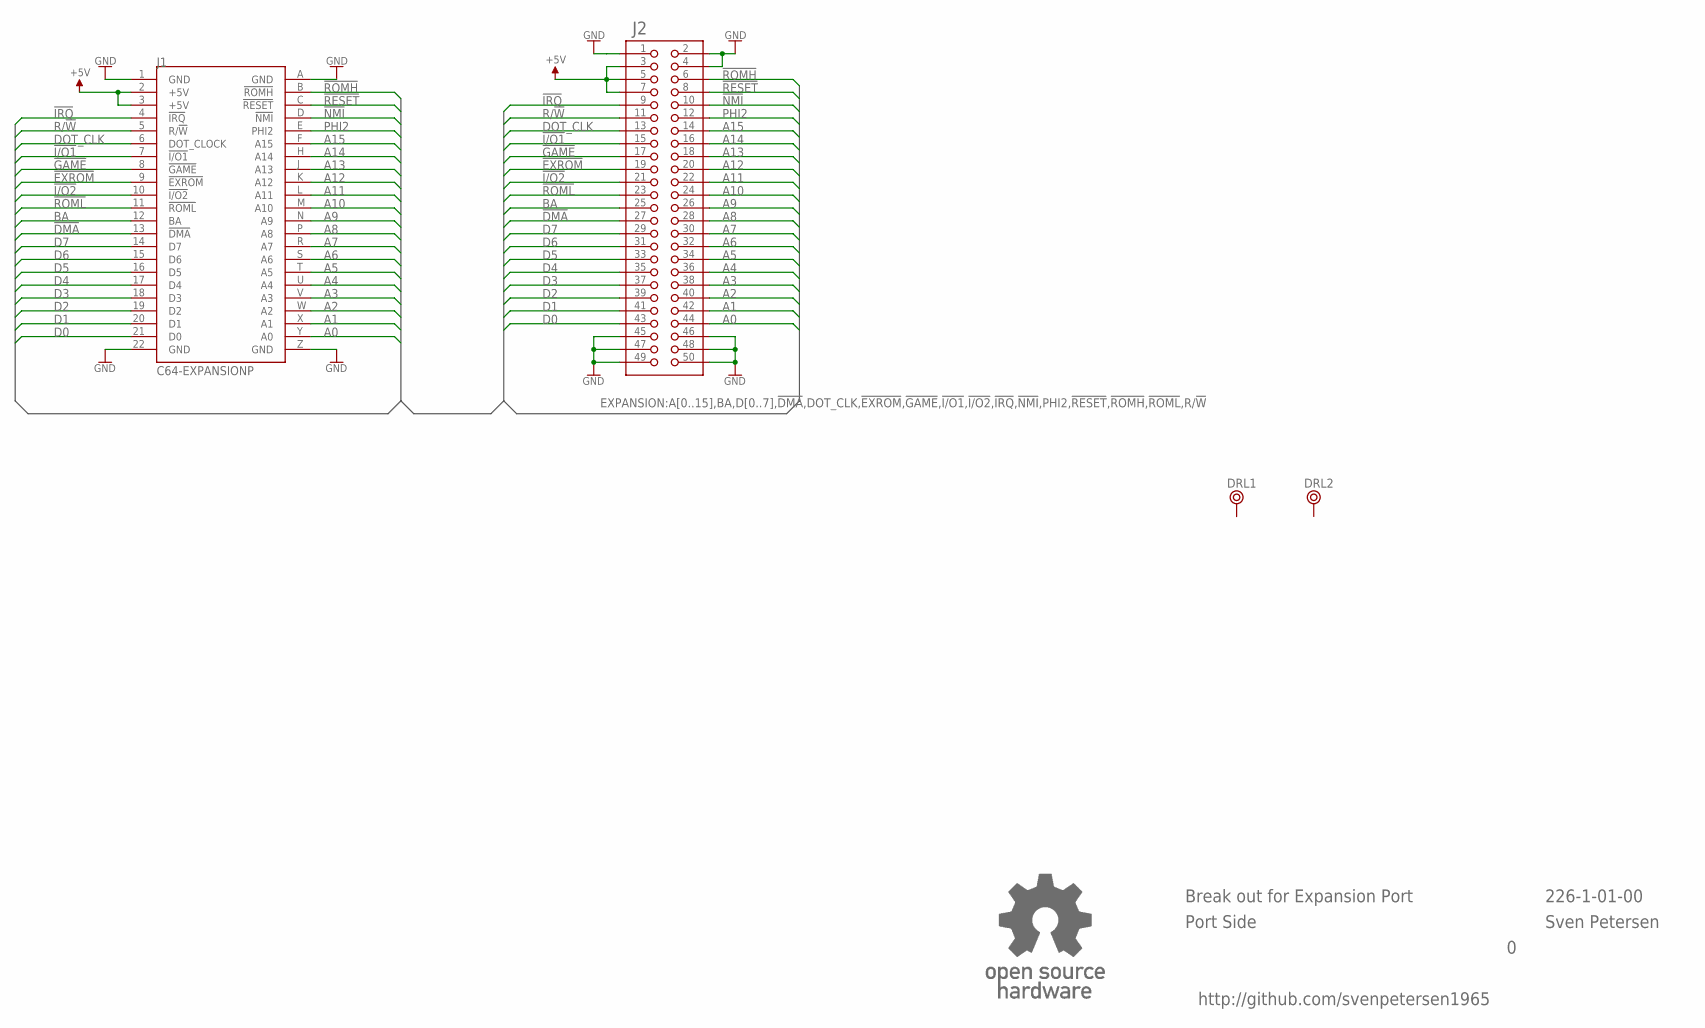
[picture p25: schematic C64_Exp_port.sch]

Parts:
DRL1, DRL2: BOHR3,3
J1: C64-EXPANSIONP; EXPPORT
J2: PINHD-2X25BOX; 2X25WV
U$22: OPEN_SOURCE_HW; OPENHW

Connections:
!DMA: J1.13 (!DMA), J2.27
!EXROM: J1.9 (!EXROM), J2.19
!GAME: J1.8 (!GAME), J2.17
!I/O1: J1.7 (!I/O1), J2.15
!I/O2: J1.10 (!I/O2), J2.21
!IRQ: J1.4 (!IRQ), J2.9
!NMI: J1.D (!NMI), J2.10
!RESET: J1.C (!RESET), J2.8
!ROMH: J1.B (!ROMH), J2.6
!ROML: J1.11 (!ROML), J2.23
+5V: J1.2 (+5V), J1.3 (+5V), J2.3, J2.5, J2.7
A0: J1.Y (A0), J2.44
A1: J1.X (A1), J2.42
A2: J1.W (A2), J2.40
A3: J1.V (A3), J2.38
A4: J1.U (A4), J2.36
A5: J1.T (A5), J2.34
A6: J1.S (A6), J2.32
A7: J1.R (A7), J2.30
A8: J1.P (A8), J2.28
A9: J1.N (A9), J2.26
A10: J1.M (A10), J2.24
A11: J1.L (A11), J2.22
A12: J1.K (A12), J2.20
A13: J1.J (A13), J2.18
A14: J1.H (A14), J2.16
A15: J1.F (A15), J2.14
BA: J1.12 (BA), J2.25
D0: J1.21 (D0), J2.43
D1: J1.20 (D1), J2.41
D2: J1.19 (D2), J2.39
D3: J1.18 (D3), J2.37
D4: J1.17 (D4), J2.35
D5: J1.16 (D5), J2.33
D6: J1.15 (D6), J2.31
D7: J1.14 (D7), J2.29
DOT_CLK: J1.6 (DOT_CLOCK), J2.13
GND: J1.1 (GND), J1.22 (GND), J1.A (GND), J1.Z (GND), J2.1, J2.2, J2.4, J2.45, J2.46, J2.47, J2.48, J2.49, J2.50
PHI2: J1.E (PHI2), J2.12
R/!W: J1.5 (R/!W), J2.11

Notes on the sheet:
Break out for Expansion Port
Sven Petersen
226-1-01-00
http://github.com/svenpetersen1965
Port Side

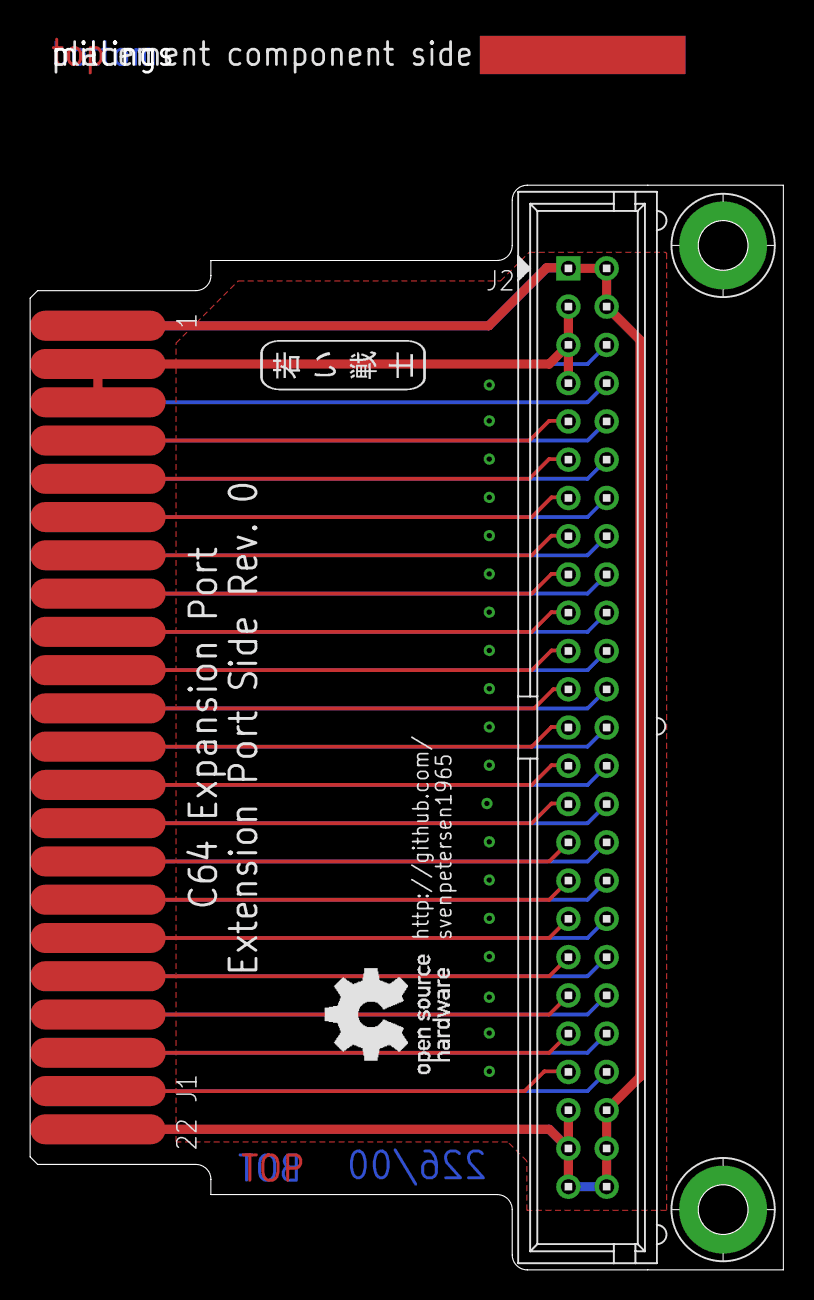
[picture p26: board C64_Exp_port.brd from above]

Board: 2 copper layers, 50.0 x 72.0 mm, 8 parts (0 on the bottom side), 40 nets.

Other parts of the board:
U$20: 2LAYER
U$21: PCB-TITLE/
U$23: SVEN_TAG

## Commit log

2026-05-25 Preliminary Release
    [C64Exp_Ext_C_BOM_v0_0.xlsx, C64_Exp_Ext_P_BOM_v0_0.xlsx, C64_Exp_cartridge.brd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]
2026-07-04 new BOM
    [C64Exp_Ext_C_BOM_v0_0.xlsx]
2026-07-04 ribbon cable drawing
